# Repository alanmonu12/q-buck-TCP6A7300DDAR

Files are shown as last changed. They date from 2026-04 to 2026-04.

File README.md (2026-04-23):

View this project on [CADLAB.io](https://cadlab.io/project/30117) or [kicanvas.org](https://kicanvas.org/?repo=https%3A%2F%2Fgithub.com%2Falanmonu12%2Fq-buck-TCP6A7300DDAR%2Ftree%2Fdevelop). 

# Q-Buck TCP6A7300DDAR EVAL BOARD MX <!-- omit in toc -->









Una placa de evaluación Open Source Hardware (OSHW) diseñada para probar y caracterizar el convertidor Buck síncrono TCP6A7300DDAR, un circuito integrado diseñado en México por QSM Semiconductores. Esta placa está pensada como un primer paso para validar el comportamiento térmico, la estabilidad del lazo de control y la eficiencia del IC bajo  condiciones reales, con miras a integrarlo en proyectos educativos e industriales más grandes.

<p align="center">
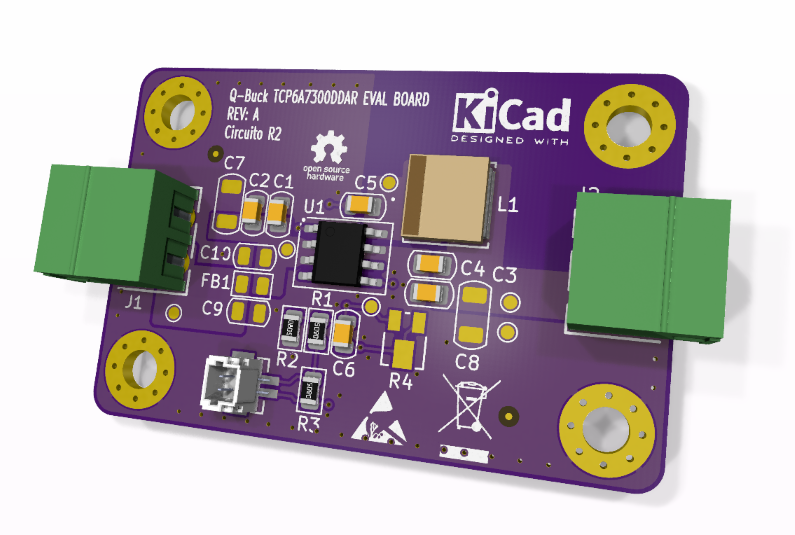
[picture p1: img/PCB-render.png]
Render 3D de la Q-Buck TCP6A7300DDAR
  
</p>

## Tabla de Contenido <!-- omit in toc -->

- [Características del IC (TCP6A7300DDAR)](#características-del-ic-tcp6a7300ddar)
- [Diseño Orientado a la Validación (Design for Testability)](#diseño-orientado-a-la-validación-design-for-testability)
- [Ecuaciones y Diseño Preliminar](#ecuaciones-y-diseño-preliminar)
- [Lista de Materiales (BOM) y Consideraciones de Ensamblaje](#lista-de-materiales-bom-y-consideraciones-de-ensamblaje)
- [Especificaciones de Manufactura y Stackup](#especificaciones-de-manufactura-y-stackup)
- [Estado del Proyecto](#estado-del-proyecto)
- [Referencias y Documentación](#referencias-y-documentación)
- [License](#license)

## Características del IC (TCP6A7300DDAR)

El núcleo de este proyecto es la evaluación en hardware del convertidor TCP6A7300DDAR, un circuito integrado diseñado y manufacturado en México. La motivación principal es impulsar la industria electrónica nacional, demostrando que es posible integrar silicio de origen local en topologías de potencia confiables.

- Voltaje de Entrada ($V_{IN}$): 3.8V a 35V
- Corriente de Salida: 3A Continuos
- Frecuencia de Conmutación: 500 kHz
- Voltaje de Referencia ($V_{REF}$): 0.8V
- Topología: Step-Down (Buck) Síncrono
- Empaquetado: SOP-8 con *Exposed Pad*

<p align="center">
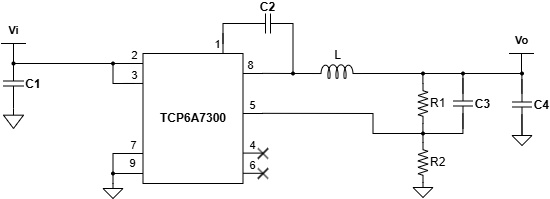
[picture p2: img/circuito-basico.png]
Circuito básico de aplicación TCP6A7300DDAR
  
  <br>
  <em>Topología básica de aplicación del IC.</em>
</p>

## Diseño Orientado a la Validación (Design for Testability)

Esta tarjeta fue pensada para ir mucho más allá de ser una simple implementación de referencia del IC TCP6A7300DDAR. Su arquitectura está pensada como un entorno de laboratorio para enseñar, experimentar y comprender a fondo los fenómenos dinámicos y electromagnéticos que rigen a las fuentes conmutadas. 

Para lograr esto, la placa integra características específicas de validación:

- **Análisis de Estabilidad y Lazo de Control:** Cuenta con un punto de inyección de señal. Esto permite aislar el lazo de retroalimentación en corriente alterna (AC) para inyectar pequeña señal y extraer el Diagrama de Bode utilizando instrumentos como el Analog Discovery 3, facilitando el estudio práctico del Margen de Fase y Ganancia.
- **Filtro Pi para Mitigación EMI:** Se integraron footprints opcionales a la entrada para conformar un filtro Pi pasivo (dos capacitores cerámicos separados por un Ferrite Bead o inductor de alta frecuencia). Esto permite a los ingenieros evaluar empíricamente la atenuación del ruido conducido, entender el filtrado de armónicos y analizar cómo la impedancia de entrada afecta la estabilidad del convertidor. 
- **Flexibilidad de Operación:** Diseñada por defecto para entregar un riel estable de 5V, incluye opciones de montaje para un potenciómetro de ajuste, esto facilita la ejecución de barridos de voltaje.

<p align="center">
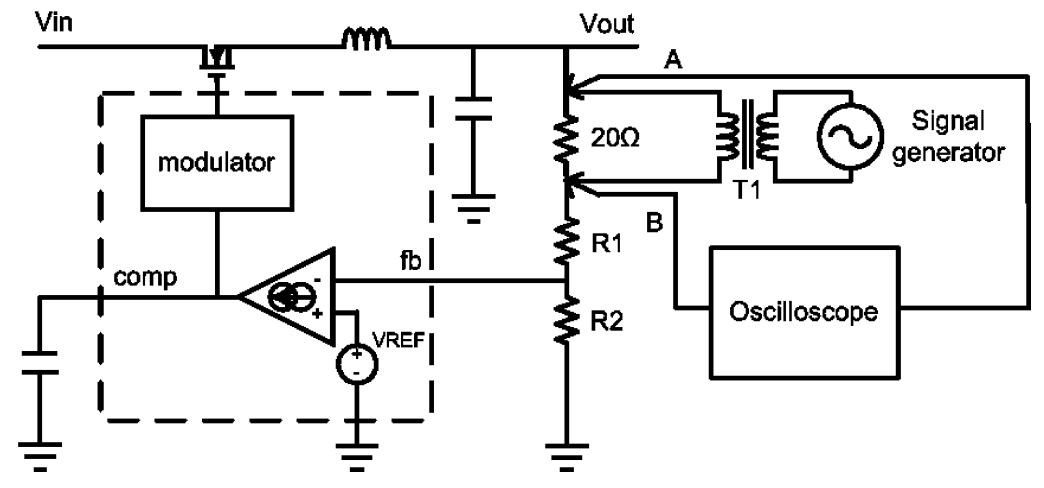
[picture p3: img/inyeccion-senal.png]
Configuración de inyección de señal para medición de lazo de control
  
  <br>
  <em> Diagrama de referencia (TI) para la inyección de pequeña señal AC en el lazo de retroalimentación. La placa de evaluación integra este arreglo físico mediante el resistor de inyección flotante y conectores SMD dedicados.</em>
</p>

## Ecuaciones y Diseño Preliminar

El circuito actual está calculado para un escenario típico de reducción de voltaje (ej. batería de $12V/24V$ a $5V$ para lógica).

**Parámetros de Diseño:**

- $V_{IN(max)} = 35V$
- $V_{OUT} = 5V$
- $I_{OUT} = 1A$
- $f_{sw} = 500 kHz$

**1. Lazo de Retroalimentación (Feedback)**

El divisor de voltaje se calcula basándose en la referencia interna de 0.8V. Asignando $R_2 = 10k\Omega$:

$$R_1 = R_2 \left( \frac{V_{OUT}}{V_{REF}} - 1 \right)$$
$$R_1 = 10k\Omega \left( \frac{5V}{0.8V} - 1 \right) = 52.5 k\Omega$$

   >[!NOTE]
   >
   > En el esquemático se utiliza el valor comercial estándar más cercano de $56k\Omega$, lo que resulta en un $V_{OUT}$ real aproximado de $5.28V$.

**2. Cálculo del Inductor ($L$)**

Se asume un rizado de corriente ($\Delta I_L$) del 30% de la corriente de salida nominal ($I_{OUT} = 2A$), resultando en $\Delta I_L = 600mA$.

$$L = \frac{V_{OUT} (V_{IN} - V_{OUT})}{V_{IN} \cdot f_{sw} \cdot \Delta I_L}$$
$$L = \frac{5V (35V - 5V)}{35V \cdot 500kHz \cdot 600mA} = 14.28 \mu H$$

   >[!NOTE]
   >
   > Se elige un valor comercial estándar de $10 \mu H$, lo que aumentará ligeramente el rizado de corriente, pero mejorará la respuesta transitoria.

**3. Capacitor de Salida ($C_{OUT}$)**

Para mantener un rizado de voltaje en la salida ($\Delta V_{OUT}$) menor a $20mV$:

$$C_{OUT} = \frac{\Delta I_L}{8 \cdot f_{sw} \cdot \Delta V_{OUT}}$$
$$C_{OUT} = \frac{600mA}{8 \cdot 500kHz \cdot 20mV} = 7.5 \mu F$$

   >[!NOTE]
   >
   > Se utiliza un valor estándar de $10 \mu F$ con un capacitor cerámico multicapa.

## Lista de Materiales (BOM) y Consideraciones de Ensamblaje

Este prototipo fue diseñado bajo una filosofía de **"tropicalización" y rápida iteración**. Todos los componentes pasivos seleccionados son de montaje superficial (SMD tamaño 0805) y están restringidos a números de parte comerciales que se pueden adquirir inmediatamente en el mercado local mexicano (ej. Unit Electronics), evitando tiempos de importación.

Reference|	Qty|	Part number|	Value|	DNP|	Footprint|	Supplier |
| :--- | :--- | :--- | :--- | :--- | :--- | :--- |
C1, C4, C5|	3|	CC0805KRX7R9BB104|	0.1uF|	|	0805_2012Metric|	[Link](https://uelectronics.com/producto/cc0805krx7r9bb104-capacitor-ceramico-0805-100nf-50v/) |
C2|	1|	UMK212ABJ225KG-T|	2.2uF|	|	0805_2012Metric|	[Link](https://uelectronics.com/producto/umk212abj225kg-t-capacitor-ceramico-0805-2-2uf-50v/) |
C3|	1|	TMK212BBJ106KG-T|	10uF|	| 0805_2012Metric|	[Link](https://uelectronics.com/producto/tmk212bbj106kg-t-capacitor-ceramico-0805-10uf-25v/) |
C6|	1|	CL21C101JBANNNC|	100pF|	|	0805_2012Metric|	[Link](https://uelectronics.com/producto/capacitor-ceramico-0805-100pf-50v-cl21c101jbannnc/) |
C7, C8|	2|	CL31B106KBHNNNE|	10uF|	DNP|	1206_3216Metric|	[Link](https://uelectronics.com/producto/cl31b106kbhnnne-capacitor-ceramico-1206-10uf-50v/) |
C9, C10|	2|	CC0805KRX7R9BB104|	0.1uF|	DNP|	0805_2012Metric|	[Link](https://uelectronics.com/producto/cc0805krx7r9bb104-capacitor-ceramico-0805-100nf-50v/) |
FB1|	1|	DNP|	DNP|	DNP|	0805_2012Metric|	|
J1, J2|	2|	691322310002|	691322310002|	|	TH |	|
J3|	1|	BM02B-SRSS-TB LFSN|	BM02B-SRSS-TB LFSN|	|	SMD|	[Link](https://uelectronics.com/producto/conectores-sh1-0mm-verticales/) |
L1|	1|	SWPA6020S100MT|	10uH|	|	IND_SWPA6020S_SNL|	[Link](https://uelectronics.com/producto/indutor-de-ferrita-10uh-1-15a-slf0403-100mtt/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) |
R1|	1|	RC0805JR-0756KL|	56K|	|	0805_2012Metric|	[Link](https://uelectronics.com/producto/resistor-56k-ohm-1-8w-smd-0805-rs-05k6802ft/) |
R2|	1|	0805W8F1002T5E|	10K|	|	0805_2012Metric|	[Link](https://uelectronics.com/producto/resistor-10k-ohm-1-8w-smd-0805-0805w8f2202t5e/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) |
R3|	1|	RTT05000JTP|	0R|	|	0805_2012Metric|	[Link](https://uelectronics.com/producto/resistor-0-ohm-1-8w-smd-0805-rtt05000jtp/) |
R4|	1|	TC33X-2-103E|	100K|	DNP|	SMD |	[Link](https://uelectronics.com/producto/trimpot-smd-10k-ohm-3x3-8mm-tc33x-2-103e/) |
U1|	1|	TCP6A7300DDAR|	TCP6A7300DDAR|	|	SOIC-8-1EP_ThermalVias|	|

> [!NOTE]
> 
> Los footprints marcados como **DNP** (Do Not Populate) en el esquemático, se dejaron intencionalmente vacíos para permitir soldar componentes adicionales durante la fase de validación en banco de pruebas.

## Especificaciones de Manufactura y Stackup

Para obtener buenos resultados térmicos y electromagnéticos, la tarjeta fue diseñada utilizando un perfil de manufactura de 4 capas estándar. El objetivo es que cualquier ingeniero pueda mandar a fabricar este diseño en casas ensambladoras de bajo costo (como JLCPCB o PCBWay) sin tener en cargos extras por procesos avanzados.

**Características Físicas de la Placa:**

* **Dimensiones:** 45.0 mm x 30.0 mm.
* **Grosor Total:** 1.6 mm.
* **Acabado Superficial:** HAL Lead-Free (HASL libre de plomo RoHS).
* **Reglas de Diseño (DRC):** Ruteo robusto con pista/separación mínima de 0.2 mm (aprox. 8 mils) y diámetro de perforación (vías) mínimo de 0.3 mm. 

**Análisis del Stackup (Cobre de 1 oz):**

* **Capa 1 (Top) - Señal y Potencia:** Aloja todos los componentes SMD, el "Hot Loop" y el nodo SW.
* **Capa 2 (In1) - Plano de Tierra Sólido (GND):** Actúa como escudo de Faraday y ruta de retorno de baja impedancia.
* **Capa 3 (In2) - Plano de Tierra (GND):** aporta masa térmica adicional para la disipación del IC. Utilizada para llevar la señal sensible de retroalimentación (Feedback) protegida entre dos planos de tierra.
* **Capa 4 (Bottom) - Ruteo y Planos Auxiliares:**  Utilizada para llevar la señal sensible de retroalimentación (Feedback).

## Estado del Proyecto

- [x] Cálculo de componentes pasivos.
- [x] Captura del Esquemático (KiCad).
- [x] Diseño del PCB (Layout y consideraciones térmicas).
- [ ] Ensamble del primer prototipo.
- [ ] Pruebas de caracterización y respuesta en frecuencia (FRA).

## Referencias y Documentación

[1]: [Basic Calculation of a Buck Converter's Power Stage (SLVA477B)](https://www.ti.com/lit/an/slva477b/slva477b.pdf)

[2]: [How to Measure the Loop Transfer Function of Power Supplies (AN-1889 / SNVA364A)](https://www.ti.com/lit/an/snva364a/snva364a.pdf)

[3]: [Analysis and Design of Input Filter for DC-DC Circuit (SNVA801)](https://www.ti.com/lit/pdf/snva801)

[4]: [Design a Second-stage Filter for Sensitive Applications (SSZT824)](https://www.ti.com/lit/pdf/sszt824)

[5]: [How to select input capacitors for a buck converter](https://www.ti.com/lit/an/slyt670/slyt670.pdf)

[6]: [Improve High-Current DC/DC Regulator EMI Performance for Free With Optimized Power Stage Layout](https://www.ti.com/lit/ab/snva803/snva803.pdf?ts=1772697173603)

[7]: [DC-DC PCB Layout Design for EMC](https://www.diodes.com/assets/App-Note-Files/AN1191-DC-DC-PCB-Layout-Design-for-EMC.pdf)

## License

This project is licensed under the CC BY-NC-SA 4.0 License. See the LICENSE file for details.

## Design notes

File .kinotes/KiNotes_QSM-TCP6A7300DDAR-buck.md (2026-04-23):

# **QSM-TCP6A7300DDAR-buck - Design Notes**

## **Overview**
<!-- Brief description of the PCB project -->

## **Schematic Notes**
<!-- Key circuit blocks, design rationale -->

## **Layout Considerations**
<!-- Layer stackup, impedance, keep-outs -->

## **Component Notes**
<!-- Click on designators like R1, C5, U3 to highlight on PCB -->

## **Power Distribution**
<!-- Power rails, decoupling strategy -->

## **Signal Integrity**
<!-- Critical nets, routing constraints -->

## **References**
<!-- Datasheets, application notes, calculations -->

---
*KiNotes - PCBtools.xyz*

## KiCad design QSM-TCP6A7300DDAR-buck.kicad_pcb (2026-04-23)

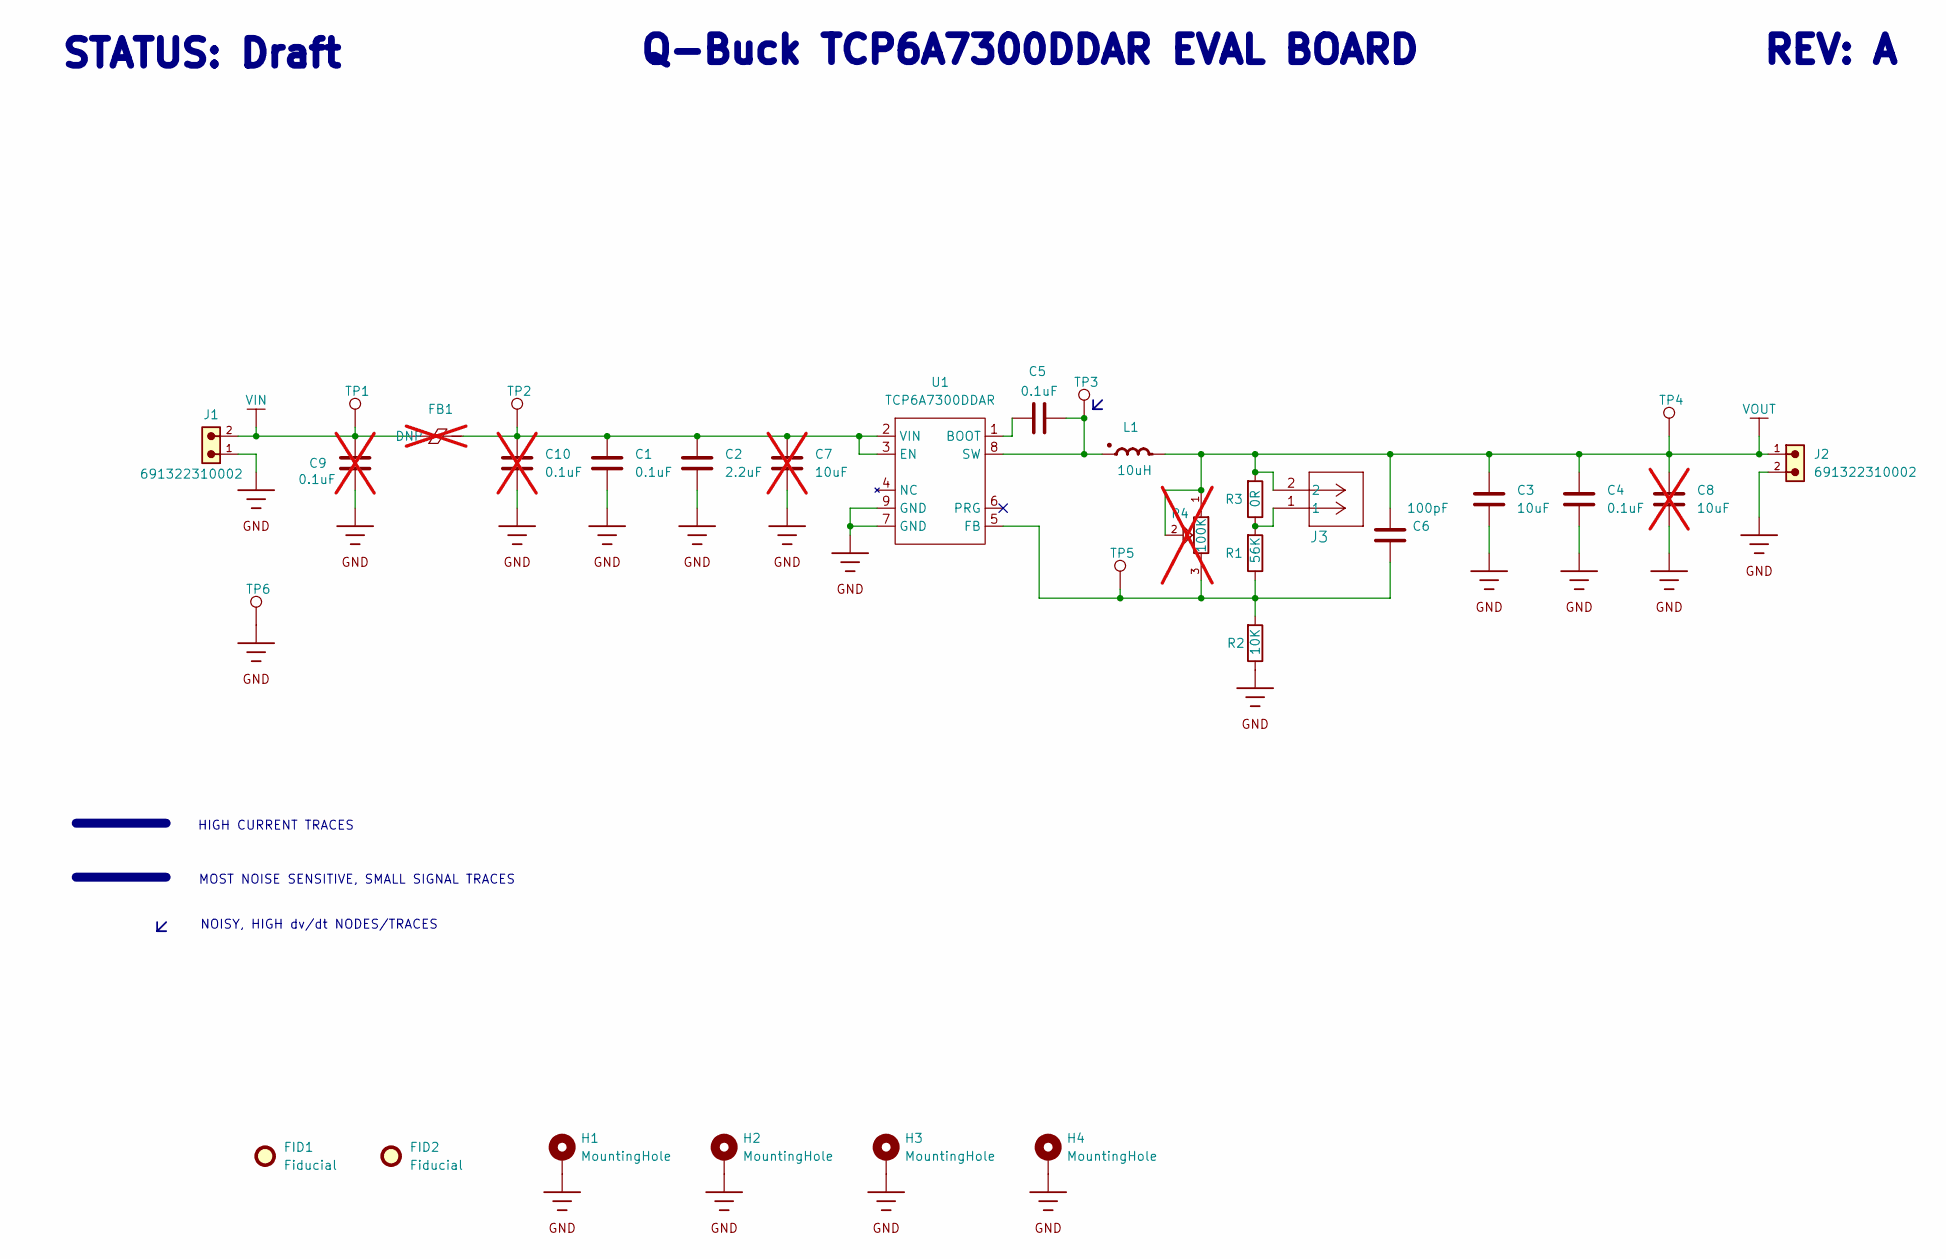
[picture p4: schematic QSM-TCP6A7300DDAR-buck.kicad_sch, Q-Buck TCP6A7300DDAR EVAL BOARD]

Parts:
C1, C4, C5: 0.1uF; C_0805_2012Metric; Tolerance ± 10%; Voltage 50V; Part number CC0805KRX7R9BB104
C2: 2.2uF; C_0805_2012Metric; Tolerance ±10%; Voltage 50V; Part number UMK212ABJ225KG-T
C3: 10uF; C_0805_2012Metric; Tolerance ±10%; Voltage 25V; Part number TMK212BBJ106KG-T
C6: 100pF; C_0805_2012Metric; Tolerance ± 5%; Voltage 50V; Part number CL21C101JBANNNC
C7, C8: 10uF; C_1206_3216Metric; Tolerance ± 10%; Voltage 50V; Part number CL31B106KBHNNNE; not fitted
C9, C10: 0.1uF; C_0805_2012Metric; Tolerance ± 10%; Voltage 50V; Part number CC0805KRX7R9BB104; not fitted
FB1: DNP; R_0805_2012Metric; Part number DNP; not fitted
FID1, FID2: Fiducial; Fiducial_0.5mm_Mask1.5mm; Part number NA
H1, H2, H3, H4: MountingHole; MountingHole_3.2mm_M3_Pad_Via; Part number NA
J1, J2: 691322310002; Part number 691322310002
J3: BM02B-SRSS-TB LFSN; BM02B-SRSS-TB_JST; Part number BM02B-SRSS-TB LFSN
L1: 10uH; IND_SWPA6020S_SNL; Tolerance ±20%; Current Rating 1.4 A; Part number SWPA6020S100MT
R1: 56K; R_0805_2012Metric; Tolerance ± 5%; Part number RC0805JR-0756KL
R2: 10K; R_0805_2012Metric; Tolerance ± 1%; Part number 0805W8F1002T5E
R3: 0R; R_0805_2012Metric; Tolerance ± 5%; Part number RTT05000JTP
R4: 100K; POT_TC33_3X3P8_BRN; Part number TC33X-2-103E; not fitted
TP1, TP2, TP3, TP4, TP5, TP6: TestPoint; TestPoint_Pad_D1.0mm; Part number NA
U1: TCP6A7300DDAR; SOIC-8-1EP_3.9x4.9mm_P1.27mm_EP2.29x3mm_ThermalVias; Part number TCP6A7300DDAR

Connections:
GND: C1.2, C2.2, C3.2, C4.2, C7.2, C8.2, C9.2, C10.2, H1.1 (1_1), H2.1 (1_1), H3.1 (1_1), H4.1 (1_1), J1.1, J2.2, R2.2, TP6.1 (1_1), U1.7 (GND), U1.9 (GND)
unnamed: C3.1, C4.1, C6.1, C8.1, J2.1, J3.2, L1.2, R3.1, R4.1, R4.2, TP4.1 (1_1)
unnamed: C9.1, FB1.1, J1.2, TP1.1 (1_1)
unnamed: J3.1, R1.1, R3.2
unnamed: C5.1, U1.1 (BOOT)
unnamed: C1.1, C2.1, C7.1, C10.1, FB1.2, TP2.1 (1_1), U1.2 (VIN), U1.3 (EN)
unnamed: C6.2, R1.2, R2.1, R4.3, TP5.1 (1_1), U1.5 (FB)
unnamed: C5.2, L1.1, TP3.1 (1_1), U1.8 (SW)

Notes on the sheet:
${TITLE}
MOST NOISE SENSITIVE, SMALL SIGNAL TRACES
REV: ${REVISION}
HIGH CURRENT TRACES
STATUS: ${COMMENT1}
NOISY, HIGH dv/dt NODES/TRACES

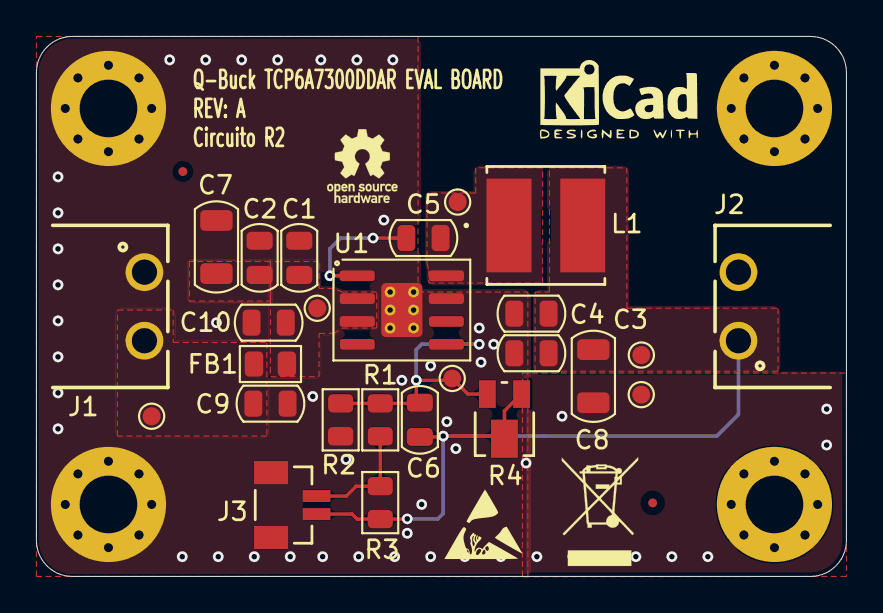
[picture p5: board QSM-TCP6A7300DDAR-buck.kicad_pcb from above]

Board: 4 copper layers, 45.0 x 30.0 mm, 32 parts (0 on the bottom side), 8 nets.

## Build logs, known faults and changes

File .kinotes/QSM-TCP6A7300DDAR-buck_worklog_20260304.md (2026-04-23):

# Work Log — QSM-TCP6A7300DDAR-buck
**Total: 0h 0m**

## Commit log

2026-02-27 feat: commit inicial con esquemático del Q-Buck TCP6A7300DDAR y documentación base
    Incluye el archivo README.md con cálculos de lazo de retroalimentación, referencias bibliográficas y el esquemático preliminar en KiCad v10.
    [QSM-TCP6A7300DDAR-buck.kicad_pcb, QSM-TCP6A7300DDAR-buck.kicad_sch]
2026-02-27 docs: identificar trazos críticos en el esquemático para ruteo
    Se agregaron colores y leyendas para diferenciar las pistas de alta corriente (rojo), señales sensibles de retroalimentación (amarillo) y nodos ruidosos con alto dv/dt. Sirve como guía visual obligat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
    [QSM-TCP6A7300DDAR-buck.kicad_sch]
2026-03-02 docs: agregar lista de materiales (BOM) y límites de hardware
    Se integró la tabla de componentes críticos con enlaces a proveedores locales para ensamble rápido. También se documentaron las consideraciones de derating físico: límite de corriente de 1.4A por sat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
    [QSM-TCP6A7300DDAR-buck.kicad_sch]
2026-03-03 feat: agregar test points en nodos críticos y referencias de filtros EMI
    Se colocaron Test Points estratégicos en el esquemático (ej. VIN, VOUT, SW y el lazo de Feedback) para facilitar las mediciones con osciloscopio y la inyección de señal. Además, se actualizó el README.md con la bibliografía de Texas Instruments sobre el Criterio de Middlebrook y el amortiguamiento de filtros LC de segunda etapa.
    [QSM-TCP6A7300DDAR-buck.kicad_pcb, QSM-TCP6A7300DDAR-buck.kicad_sch]
2026-03-04 feat(layout): [WIP] ruteo inicial de polígonos de potencia en 4 capas
    Se definió el stackup simétrico de 4 capas (SIG-GND-GND-SIG) y se realizó el floorplanning. Se trazaron los polígonos preliminares de alta corriente (VIN, SW, VOUT) en la capa Top. El ruteo de la señ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
    [QSM-TCP6A7300DDAR-buck.kicad_pcb, QSM-TCP6A7300DDAR-buck.kicad_sch]
2026-03-06 feat(hardware): optimización de hot-loops, conector de inyección de señal y actualización de docs
    Esquemático y PCB:
    - Reubicación jerárquica de capacitores de entrada y salida para minimizar el área del Hot Loop y reducir el ESL, alineado a notas de aplicación de PI.
    - Adición de conector SMD JST SH (BM02B-SRSS-TB) en paralelo a la resistencia de inyección para facilitar la medición del lazo de control (Bode Plot).
    Documentación (README):
    - Integración de 'badges' de estado y especificaciones técnicas.
    - Redacción de la justificación técnica del layout (Control EMI y Hot Loops) referenciando bibliografía de TI.
    - Adición de render 3D de la placa y diagrama esquemático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
    [QSM-TCP6A7300DDAR-buck.kicad_pcb, QSM-TCP6A7300DDAR-buck.kicad_sch]
2026-03-06 chore(project): preparación para manufactura (BOM, stackup PCB y docs)
    - Refactorización de la narrativa del proyecto enfocándose en la validación empírica y el desarrollo de la industria nacional.
    - Integración de la sección 'Design for Testability' (DFT) y justificación técnica del stackup de 4 capas.
    Layout (PCB):
    - Adición de las tablas de características de la placa y detalles del stackup (capas, grosores de FR4/Prepreg y cobre) en la capa de dibujo para referencia del fabricante.
    Proyecto y Esquemático:
    - Ajuste y actualización de los metadatos de los componentes para habilitar una generación de BOM limpia y automatizada.
    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
    [QSM-TCP6A7300DDAR-buck.kicad_pcb, QSM-TCP6A7300DDAR-buck.kicad_sch]
2026-03-06 build(mfg): automatización de salidas de manufactura mediante Jobsets
    Integración de archivos de configuración (Jobsets) para estandarizar y automatizar la generación del paquete de producción.
    Se automatizan las siguientes salidas con reglas predefinidas:
    - Archivos Gerber (Cobre, Máscaras, Serigrafía, Bordes).
    - Archivos de taladrado Excellon (Drill files PTH/NPTH).
    - Lista de Materiales (BOM) formateada para ensamble.
    - Archivo de Posición de Componentes (CPL / Pick and Place) para procesos de Pick & Place SMD.
    Este flujo garantiza consistencia entre el diseño fuente y los archivos enviados a la casa fabricante (JLCPCB), eliminando el error humano en la fase de ploteo.
    [QSM-TCP6A7300DDAR-buck.kicad_pcb]
